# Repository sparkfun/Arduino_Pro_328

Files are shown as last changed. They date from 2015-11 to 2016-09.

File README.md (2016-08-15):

Arduino Pro 328
========================================

Arduino Pro 328

[*Arduino Pro 328 (DEV-10914)*](https://www.sparkfun.com/products/10914)

Arduino Pro does not come with connectors populated so that you can solder in any connector or wire with any orientation you need. 
We recommend first time Arduino users start with the Uno R3. It’s a great board that will get you up and running quickly. 
The Arduino Pro series is meant for users that understand the limitations of system voltage, lack of connectors, and USB off board.

Repository Contents
-------------------

* **/Hardware** - Eagle design files (.brd, .sch)
* **/Production** - Production panel files (.brd)

Documentation
--------------
* **[SparkFun Fritzing repo](https://github.com/sparkfun/Fritzing_Parts)** - Fritzing diagrams for SparkFun products.
* **[SparkFun 3D Model repo](https://github.com/sparkfun/3D_Models)** - 3D models of SparkFun products. 

Product Versions
----------------
* [3.3V/8MHz: DEV-10914](https://www.sparkfun.com/products/10914)- 3.3V/8MHz version of the Arduino Pro. 
* [5V/16MHz: DEV-10915] (https://www.sparkfun.com/products/10915)- 5V/16MHz version of the Arduino Pro. 

Revision History
----------------
Changes to v14 (date code: 8-24-11)
* updated library to increase annular ring size on all thru-hole pads (including package change on buzzer PTH)
* reposition 6x1 serial header to no longer overhang board
* BOM CHANGE - changes smd slide switch to stronger package with side mount tabs

Changes to v15 (date code: 9-21-11)
* changed package on the Buzzer to not include silk

Changes to v16 (date code: 12-20-11)
* Added OSHW logo

Changes to v17
* Added juicy silk graphics

Changes to v18
* Widened hard-to-read silk text

License Information
-------------------

This product is _**open source**_! 

Please review the LICENSE.md file for license information. 

If you have any questions or concerns on licensing, please contact techsupport@sparkfun.com.

Distributed as-is; no warranty is given.

- Your friends at SparkFun.

_**Note:** A portion of this sale is given back to Arduino LLC to help fund continued development of new tools and new IDE features._

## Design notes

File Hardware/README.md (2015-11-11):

Arduino Pro Design Files
=====================================

The .sch and .brd files hare are Eagle CAD schematic and PCB design files from SparkFun Electronics.
A freeware version of Eagle can be found [here](http://www.cadsoftusa.com/download-eagle/freeware/).

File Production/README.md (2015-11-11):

SparkFun Arduino Pro Production Files
=========================================

These are the production files SparkFun uses for printing PCBs.

License Information
-------------------
This product is open source! 

The hardware is released under [Creative Commons ShareAlike 4.0 International](https://creativecommons.org/licenses/by-sa/4.0/).

Please use, reuse, and modify these files as you see fit. Please maintain attribution to SparkFun Electronics and release anything derivative under the same license.

Distributed as-is; no warranty is given.

- Your friends at SparkFun.

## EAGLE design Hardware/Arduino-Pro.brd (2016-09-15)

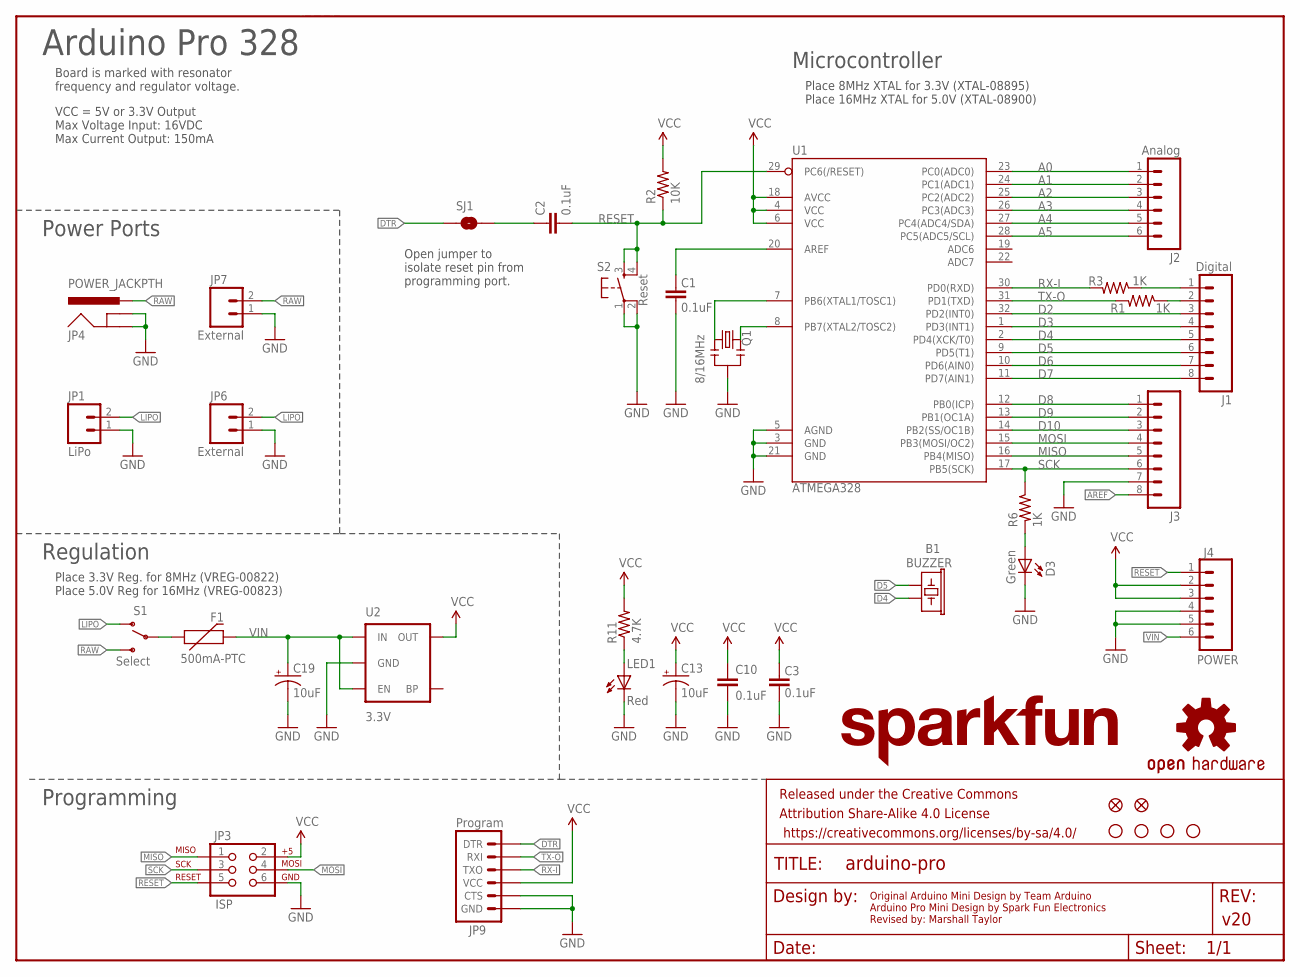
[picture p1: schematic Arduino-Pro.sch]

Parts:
B1: BUZZER; BUZZER-12MM-NS-KIT
C1, C2, C3, C10: 0.1uF; 0402-CAP
C13, C19: 10uF; EIA3216
D3: Green; LED-0603
F1: 500mA-PTC; PTC-1206
FRAME2: FRAME-LETTER; CREATIVE_COMMONS
J1: Digital; 1X08
J2: Analog; 1X06
J3: M081X08; 1X08
J4: POWER; 1X06
JP1: LiPo; JST-2-SMD
JP2, JP5: FIDUCIAL1X2.5; FIDUCIAL-1X2.5
JP3: ISP; 2X3
JP4: POWER_JACKPTH; POWER_JACK_PTH
JP6, JP7: External; 1X02
JP9: Program; 1X06-SMD
LED1: Red; LED-0603
Q1: 8/16MHz; RESONATOR-SMD
R1, R3, R6: 1K; 0402-RES
R2: 10K; 0402-RES
R11: 4.7K; 0402-RES
S1: Select; SWITCH-SPST-SMD-A
S2: Reset; TACTILE_SWITCH_SMD
SJ1: SOLDERJUMPERNC3; SJ_2S-NOTRACE
U1: ATMEGA328; TQFP32-08
U2: 3.3V; SOT23-5
U$1, U$3, U$9, U$10: STAND-OFF

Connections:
A0: J2.1, U1.23 (PC0(ADC0))
A1: J2.2, U1.24 (PC1(ADC1))
A2: J2.3, U1.25 (PC2(ADC2))
A3: J2.4, U1.26 (PC3(ADC3))
A4: J2.5, U1.27 (PC4(ADC4/SDA))
A5: J2.6, U1.28 (PC5(ADC5/SCL))
AREF: C1.2, J3.8, U1.20 (AREF)
D2: J1.3, U1.32 (PD2(INT0))
D3: J1.4, U1.1 (PD3(INT1))
D4: B1.- (2), J1.5, U1.2 (PD4(XCK/T0))
D5: B1.+ (1), J1.6, U1.9 (PD5(T1))
D6: J1.7, U1.10 (PD6(AIN0))
D7: J1.8, U1.11 (PD7(AIN1))
D8: J3.1, U1.12 (PB0(ICP))
D9: J3.2, U1.13 (PB1(OC1A))
D10: J3.3, U1.14 (PB2(SS/OC1B))
DTR: JP9.1 (DTR), SJ1.1
GND: C1.1, C3.1, C10.2, C13.C (-), C19.C (-), D3.C, J3.7, J4.4, J4.5, JP1.1, JP3.6, JP4.GND, JP4.GNDBREAK, JP6.1, JP7.1, JP9.5 (CTS), JP9.6 (GND), LED1.C, Q1.2, S2.1, S2.2, U1.3 (GND), U1.5 (AGND), U1.21 (GND), U2.2 (GND)
LIPO: JP1.2, JP6.2, S1.1 (O)
MISO: J3.5, JP3.1, U1.16 (PB4(MISO))
MOSI: J3.4, JP3.4, U1.15 (PB3(MOSI/OC2))
unnamed: C2.1, SJ1.2
unnamed: Q1.1, U1.8 (PB7(XTAL2/TOSC2))
unnamed: Q1.3, U1.7 (PB6(XTAL1/TOSC1))
unnamed: D3.A, R6.2
unnamed: F1.1, S1.2
unnamed: LED1.A, R11.1
RAW: JP4.PWR, JP7.2, S1.3 (S)
RESET: C2.2, J4.1, JP3.5, R2.1, S2.3, S2.4, U1.29 (PC6(/RESET))
RX-I: JP9.3 (TXO), R3.2, U1.30 (PD0(RXD))
RX-IP: J1.2, R1.1
SCK: J3.6, JP3.3, R6.1, U1.17 (PB5(SCK))
TX-O: JP9.2 (RXI), R1.2, U1.31 (PD1(TXD))
TX-OP: J1.1, R3.1
VCC: C3.2, C10.1, C13.A (+), J4.2, J4.3, JP3.2, JP9.4 (VCC), R2.2, R11.2, U1.4 (VCC), U1.6 (VCC), U1.18 (AVCC), U2.5 (OUT)
VIN: C19.A (+), F1.2, J4.6, U2.1 (IN), U2.3 (EN)

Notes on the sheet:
VCC = 5V or 3.3V Output Max Voltage Input: 16VDC Max Current Output: 150mA
Board is marked with resonator frequency and regulator voltage.
v20
Original Arduino Mini Design by Team Arduino Arduino Pro Mini Design by Spark Fun Electronics Revised by: Marshall Taylor
Power Ports
Regulation
Programming
Microcontroller
Arduino Pro 328
Open jumper to isolate reset pin from programming port.
Place 8MHz XTAL for 3.3V (XTAL-08895) Place 16MHz XTAL for 5.0V (XTAL-08900)
Place 3.3V Reg. for 8MHz (VREG-00822) Place 5.0V Reg for 16MHz (VREG-00823)

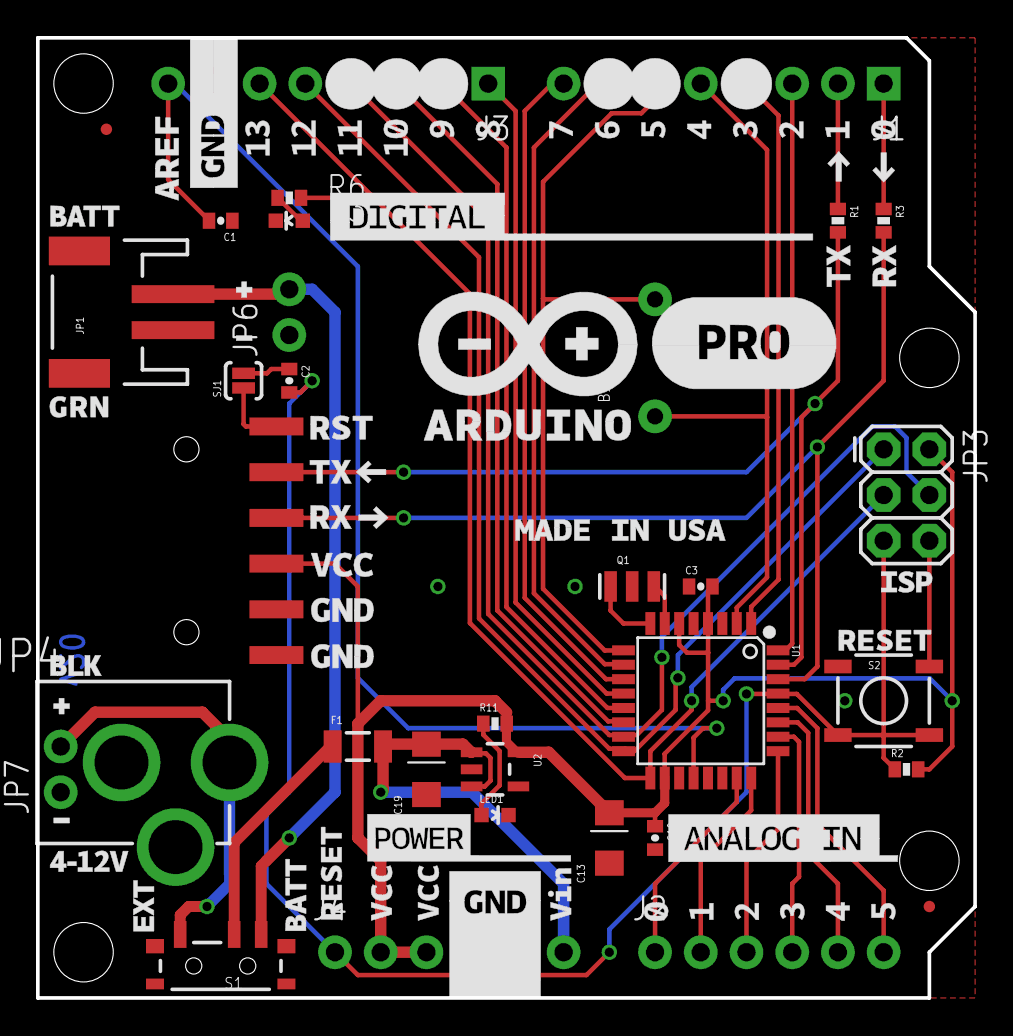
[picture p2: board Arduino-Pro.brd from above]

Board: 2 copper layers, 52.1 x 53.3 mm, 38 parts (0 on the bottom side), 36 nets.

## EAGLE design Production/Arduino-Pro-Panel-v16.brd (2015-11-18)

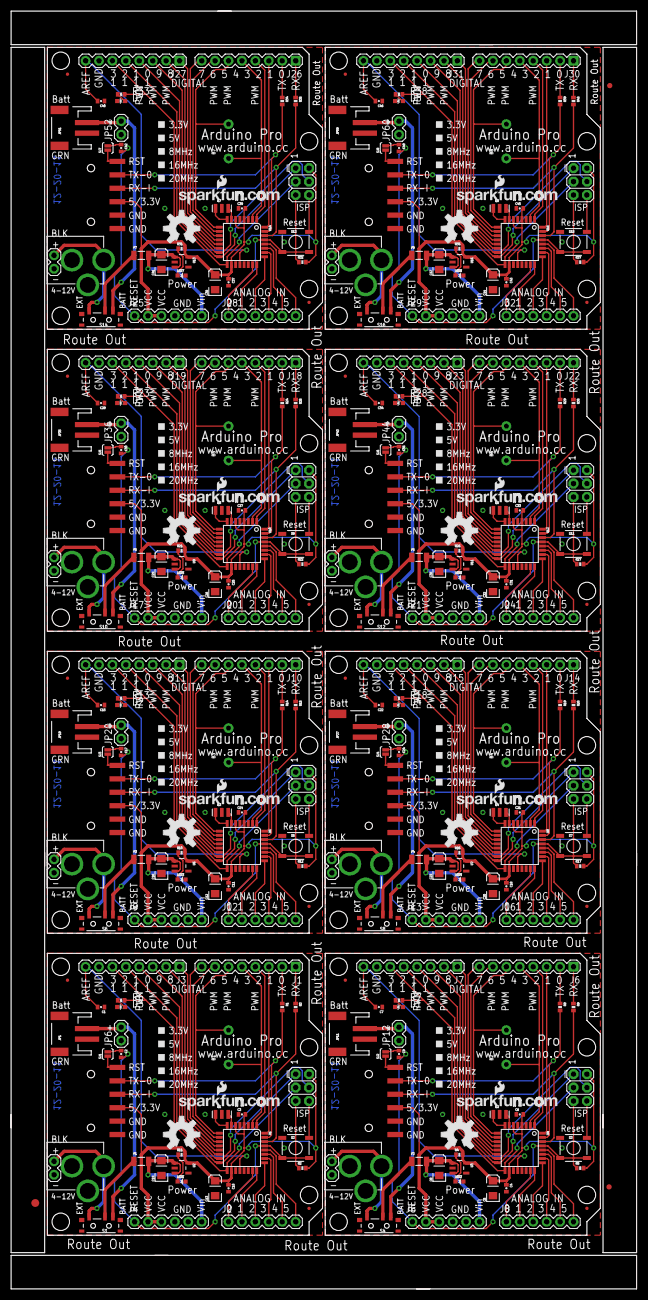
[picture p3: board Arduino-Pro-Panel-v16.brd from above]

Board: 2 copper layers, 118.4 x 241.8 mm, 315 parts (0 on the bottom side), 288 nets.

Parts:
B1, B2, B3, B4, B5, B6, B7, B8: BUZZER; BUZZER-12MM-NS-KIT
C1, C2, C3, C4, C6, C7, C9, C10, C11, C14, C15, C17, C18, C21, C22, C24, C25, C27, C28, C30, C31, C33, C34, C36, C37, C39, C40, C42, C43, C45, C46, C48: 0.1uF; 0402-CAP
C5, C8, C12, C13, C16, C19, C20, C23, C26, C29, C32, C35, C38, C41, C44, C47: 10uF; EIA3216
D1, D2, D3, D4, D5, D6, D7, D8: Green; LED-0603
E$1: FIDUCIAL-1.5X3
E$5, E$7: FIDUCIAL-1X2
F1, F2, F3, F4, F5, F6, F7, F8: 500mA-PTC; PTC-1206
J1, J6, J10, J14, J18, J22, J26, J30: Digital; 1X08
J2, J8, J12, J16, J20, J24, J28, J32: Analog; 1X06
J3, J7, J11, J15, J19, J23, J27, J31: 1X08
J4, J5, J9, J13, J17, J21, J25, J29: POWER; 1X06
JP1, JP11, JP19, JP27, JP35, JP43, JP51, JP59: LiPo; JST-2-SMD
JP2, JP5, JP15, JP16, JP23, JP24, JP31, JP32, JP39, JP40, JP47, JP48, JP55, JP56, JP63, JP64: FIDUCIAL1X2.5; FIDUCIAL-1X2.5
JP3, JP10, JP18, JP26, JP34, JP42, JP50, JP58: ISP; 2X3
JP4, JP8, JP17, JP25, JP33, JP41, JP49, JP57: POWER_JACKPTH; POWER_JACK_PTH
JP6, JP7, JP12, JP13, JP20, JP21, JP28, JP29, JP36, JP37, JP44, JP45, JP52, JP53, JP60, JP61: External; 1X02
JP9, JP14, JP22, JP30, JP38, JP46, JP54, JP62: Program; 1X06-SMD
LED1, LED2, LED3, LED4, LED5, LED6, LED7, LED8: Red; LED-0603
Q1, Q2, Q3, Q4, Q5, Q6, Q7, Q8: RESONATORSMD; RESONATOR-SMD
R1, R3, R6, R7, R8, R9, R13, R14, R15, R18, R19, R20, R23, R24, R25, R28, R29, R30, R33, R34, R35, R38, R39, R40: 1K; 0402-RES
R2, R5, R12, R17, R22, R27, R32, R37: 10K; 0402-RES
R4, R10, R11, R16, R21, R26, R31, R36: 4.7K; 0402-RES
S1, S4, S6, S8, S10, S12, S14, S16: Select; SWITCH-SPST-SMD-A
S2, S3, S5, S7, S9, S11, S13, S15: Reset; TACTILE_SWITCH_SMD
SJ1, SJ2, SJ3, SJ4, SJ5, SJ6, SJ7, SJ8: SOLDERJUMPERNC3; SJ_2S-NOTRACE
U1, U4, U6, U8, U10, U12, U14, U16: ATMEGA328; TQFP32-08
U2, U3, U5, U7, U9, U11, U13, U15: 3.3V; SOT23-5
U$1, U$3, U$4, U$5, U$7, U$8, U$9, U$10, U$13, U$14, U$16, U$17, U$19, U$20, U$22, U$23, U$25, U$26, U$28, U$29, U$31, U$32, U$34, U$35, U$37, U$38, U$40, U$41, U$43, U$44, U$46, U$47: STAND-OFF
U$2, U$12, U$18, U$24, U$30, U$36, U$42, U$48: OSHW-LOGOL; OSHW-LOGO-L
U$6, U$11, U$15, U$21, U$27, U$33, U$39, U$45: LOGO-SFENEW; SFE-NEW-WEBLOGO

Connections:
A0: J2.1, U1.23
A1: J2.2, U1.24
A2: J2.3, U1.25
A3: J2.4, U1.26
A4: J2.5, U1.27
A5: J2.6, U1.28
A6: J8.6, U4.28
A7: J8.5, U4.27
A8: J8.4, U4.26
A9: J8.3, U4.25
A10: J8.2, U4.24
A11: J8.1, U4.23
A12: J12.6, U6.28
A13: J12.5, U6.27
A14: J12.4, U6.26
A15: J12.3, U6.25
A16: J12.2, U6.24
A17: J12.1, U6.23
A18: J16.6, U8.28
A19: J16.5, U8.27
A20: J16.4, U8.26
A21: J16.3, U8.25
A22: J16.2, U8.24
A23: J16.1, U8.23
A24: J20.6, U10.28
A25: J20.5, U10.27
A26: J20.4, U10.26
A27: J20.3, U10.25
A28: J20.2, U10.24
A29: J20.1, U10.23
A30: J24.6, U12.28
A31: J24.5, U12.27
A32: J24.4, U12.26
A33: J24.3, U12.25
A34: J24.2, U12.24
A35: J24.1, U12.23
A36: J28.6, U14.28
A37: J28.5, U14.27
A38: J28.4, U14.26
A39: J28.3, U14.25
A40: J28.2, U14.24
A41: J28.1, U14.23
A42: J32.6, U16.28
A43: J32.5, U16.27
A44: J32.4, U16.26
A45: J32.3, U16.25
A46: J32.2, U16.24
A47: J32.1, U16.23
AREF: C1.2, J3.8, U1.20
AREF1: C7.2, J7.8, U4.20
AREF2: C15.2, J11.8, U6.20
AREF3: C22.2, J15.8, U8.20
AREF4: C28.2, J19.8, U10.20
AREF5: C34.2, J23.8, U12.20
AREF6: C40.2, J27.8, U14.20
AREF7: C46.2, J31.8, U16.20
D1: J7.3, U4.14
D2: J1.3, U1.32
D3: J1.4, U1.1
D4: B1.-, J1.5, U1.2
D5: B1.+, J1.6, U1.9
D6: J1.7, U1.10
D7: J1.8, U1.11
D8: J3.1, U1.12
D9: J3.2, U1.13
D10: J3.3, U1.14
D11: J7.2, U4.13
D12: J7.1, U4.12
D13: J6.8, U4.11
D14: J6.7, U4.10
D15: B2.+, J6.6, U4.9
D16: B2.-, J6.5, U4.2
D17: J6.4, U4.1
D18: J6.3, U4.32
D19: J11.3, U6.14
D20: J11.2, U6.13
D21: J11.1, U6.12
D22: J10.8, U6.11
D23: J10.7, U6.10
D24: B3.+, J10.6, U6.9
D25: B3.-, J10.5, U6.2
D26: J10.4, U6.1
D27: J10.3, U6.32
D28: J15.3, U8.14
D29: J15.2, U8.13
D30: J15.1, U8.12
D31: J14.8, U8.11
D32: J14.7, U8.10
D33: B4.+, J14.6, U8.9
D34: B4.-, J14.5, U8.2
D35: J14.4, U8.1
D36: J14.3, U8.32
D37: J19.3, U10.14
D38: J19.2, U10.13
D39: J19.1, U10.12
D40: J18.8, U10.11
D41: J18.7, U10.10
D42: B5.+, J18.6, U10.9
D43: B5.-, J18.5, U10.2
D44: J18.4, U10.1
D45: J18.3, U10.32
D46: J23.3, U12.14
D47: J23.2, U12.13
D48: J23.1, U12.12
D49: J22.8, U12.11
D50: J22.7, U12.10
D51: B6.+, J22.6, U12.9
D52: B6.-, J22.5, U12.2
D53: J22.4, U12.1
D54: J22.3, U12.32
D55: J27.3, U14.14
D56: J27.2, U14.13
D57: J27.1, U14.12
D58: J26.8, U14.11
D59: J26.7, U14.10
D60: B7.+, J26.6, U14.9
D61: B7.-, J26.5, U14.2
D62: J26.4, U14.1
D63: J26.3, U14.32
D64: J31.3, U16.14
D65: J31.2, U16.13
D66: J31.1, U16.12
D67: J30.8, U16.11
D68: J30.7, U16.10
D69: B8.+, J30.6, U16.9
D70: B8.-, J30.5, U16.2
D71: J30.4, U16.1
D72: J30.3, U16.32
DTR: JP9.1, SJ1.1
DTR1: JP14.1, SJ2.1
DTR2: JP22.1, SJ3.1
DTR3: JP30.1, SJ4.1
DTR4: JP38.1, SJ5.1
DTR5: JP46.1, SJ6.1
DTR6: JP54.1, SJ7.1
DTR7: JP62.1, SJ8.1
GND: C1.1, C3.1, C10.2, C13.C, C19.C, D3.C, J3.7, J4.4, J4.5, JP1.1, JP3.6, JP4.GND, JP4.GNDBREAK, JP6.1, JP7.1, JP9.5, JP9.6, LED1.C, Q1.2, S2.1, S2.2, U1.3, U1.5, U1.21, U2.2
GND1: C4.2, C5.C, C6.1, C7.1, C8.C, D1.C, J5.4, J5.5, J7.7, JP8.GND, JP8.GNDBREAK, JP10.6, JP11.1, JP12.1, JP13.1, JP14.5, JP14.6, LED2.C, Q2.2, S3.1, S3.2, U3.2, U4.3, U4.5, U4.21
GND2: C11.2, C12.C, C14.1, C15.1, C16.C, D2.C, J9.4, J9.5, J11.7, JP17.GND, JP17.GNDBREAK, JP18.6, JP19.1, JP20.1, JP21.1, JP22.5, JP22.6, LED3.C, Q3.2, S5.1, S5.2, U5.2, U6.3, U6.5, U6.21
GND3: C18.2, C20.C, C21.1, C22.1, C23.C, D4.C, J13.4, J13.5, J15.7, JP25.GND, JP25.GNDBREAK, JP26.6, JP27.1, JP28.1, JP29.1, JP30.5, JP30.6, LED4.C, Q4.2, S7.1, S7.2, U7.2, U8.3, U8.5, U8.21
GND4: C25.2, C26.C, C27.1, C28.1, C29.C, D5.C, J17.4, J17.5, J19.7, JP33.GND, JP33.GNDBREAK, JP34.6, JP35.1, JP36.1, JP37.1, JP38.5, JP38.6, LED5.C, Q5.2, S9.1, S9.2, U9.2, U10.3, U10.5, U10.21
GND5: C31.2, C32.C, C33.1, C34.1, C35.C, D6.C, J21.4, J21.5, J23.7, JP41.GND, JP41.GNDBREAK, JP42.6, JP43.1, JP44.1, JP45.1, JP46.5, JP46.6, LED6.C, Q6.2, S11.1, S11.2, U11.2, U12.3, U12.5, U12.21
GND6: C37.2, C38.C, C39.1, C40.1, C41.C, D7.C, J25.4, J25.5, J27.7, JP49.GND, JP49.GNDBREAK, JP50.6, JP51.1, JP52.1, JP53.1, JP54.5, JP54.6, LED7.C, Q7.2, S13.1, S13.2, U13.2, U14.3, U14.5, U14.21
GND7: C43.2, C44.C, C45.1, C46.1, C47.C, D8.C, J29.4, J29.5, J31.7, JP57.GND, JP57.GNDBREAK, JP58.6, JP59.1, JP60.1, JP61.1, JP62.5, JP62.6, LED8.C, Q8.2, S15.1, S15.2, U15.2, U16.3, U16.5, U16.21
LIPO: JP1.2, JP6.2, S1.1
LIPO1: JP11.2, JP12.2, S4.1
LIPO2: JP19.2, JP20.2, S6.1
LIPO3: JP27.2, JP28.2, S8.1
LIPO4: JP35.2, JP36.2, S10.1
LIPO5: JP43.2, JP44.2, S12.1
LIPO6: JP51.2, JP52.2, S14.1
LIPO7: JP59.2, JP60.2, S16.1
MISO: J3.5, JP3.1, U1.16
MISO1: J7.5, JP10.1, U4.16
MISO2: J11.5, JP18.1, U6.16
MISO3: J15.5, JP26.1, U8.16
MISO4: J19.5, JP34.1, U10.16
MISO5: J23.5, JP42.1, U12.16
MISO6: J27.5, JP50.1, U14.16
MISO7: J31.5, JP58.1, U16.16
MOSI: J3.4, JP3.4, U1.15
MOSI1: J7.4, JP10.4, U4.15
MOSI2: J11.4, JP18.4, U6.15
MOSI3: J15.4, JP26.4, U8.15
MOSI4: J19.4, JP34.4, U10.15
MOSI5: J23.4, JP42.4, U12.15
MOSI6: J27.4, JP50.4, U14.15
MOSI7: J31.4, JP58.4, U16.15
unnamed: C2.1, SJ1.2
unnamed: LED2.A, R4.1
unnamed: Q1.1, U1.8
unnamed: Q1.3, U1.7
unnamed: D1.A, R7.2
unnamed: F2.1, S4.2
unnamed: D3.A, R6.2
unnamed: Q2.1, U4.8
unnamed: Q2.3, U4.7
unnamed: C9.1, SJ2.2
unnamed: LED3.A, R10.1
unnamed: D2.A, R13.2
unnamed: F3.1, S6.2
unnamed: Q3.1, U6.8
unnamed: Q3.3, U6.7
unnamed: C17.1, SJ3.2
unnamed: LED4.A, R16.1
unnamed: D4.A, R18.2
unnamed: F4.1, S8.2
unnamed: Q4.1, U8.8
unnamed: Q4.3, U8.7
unnamed: C24.1, SJ4.2
unnamed: LED5.A, R21.1
unnamed: D5.A, R23.2
unnamed: F1.1, S1.2
unnamed: F5.1, S10.2
unnamed: Q5.1, U10.8
unnamed: Q5.3, U10.7
unnamed: C30.1, SJ5.2
unnamed: LED6.A, R26.1
unnamed: D6.A, R28.2
unnamed: F6.1, S12.2
unnamed: Q6.1, U12.8
unnamed: Q6.3, U12.7
unnamed: C36.1, SJ6.2
unnamed: LED7.A, R31.1
unnamed: D7.A, R33.2
unnamed: LED1.A, R11.1
unnamed: F7.1, S14.2
unnamed: Q7.1, U14.8
unnamed: Q7.3, U14.7
unnamed: C42.1, SJ7.2
unnamed: LED8.A, R36.1
unnamed: D8.A, R38.2
unnamed: F8.1, S16.2
unnamed: Q8.1, U16.8
unnamed: Q8.3, U16.7
unnamed: C48.1, SJ8.2
RAW: JP4.PWR, JP7.2, S1.3
RAW1: JP8.PWR, JP13.2, S4.3
RAW2: JP17.PWR, JP21.2, S6.3
RAW3: JP25.PWR, JP29.2, S8.3
RAW4: JP33.PWR, JP37.2, S10.3
RAW5: JP41.PWR, JP45.2, S12.3
RAW6: JP49.PWR, JP53.2, S14.3
RAW7: JP57.PWR, JP61.2, S16.3
RESET: C2.2, J4.1, JP3.5, R2.1, S2.3, S2.4, U1.29
RESET1: C9.2, J5.1, JP10.5, R5.1, S3.3, S3.4, U4.29
RESET2: C17.2, J9.1, JP18.5, R12.1, S5.3, S5.4, U6.29
RESET3: C24.2, J13.1, JP26.5, R17.1, S7.3, S7.4, U8.29
RESET4: C30.2, J17.1, JP34.5, R22.1, S9.3, S9.4, U10.29
RESET5: C36.2, J21.1, JP42.5, R27.1, S11.3, S11.4, U12.29
RESET6: C42.2, J25.1, JP50.5, R32.1, S13.3, S13.4, U14.29
RESET7: C48.2, J29.1, JP58.5, R37.1, S15.3, S15.4, U16.29
RX-I: JP9.3, R3.2, U1.30
RX-I1: JP14.3, R9.2, U4.30
RX-I2: JP22.3, R15.2, U6.30
RX-I3: JP30.3, R20.2, U8.30
RX-I4: JP38.3, R25.2, U10.30
RX-I5: JP46.3, R30.2, U12.30
RX-I6: JP54.3, R35.2, U14.30
RX-I7: JP62.3, R40.2, U16.30
RX-IP: J1.2, R1.1
RX-IP1: J6.2, R8.1
RX-IP2: J10.2, R14.1
RX-IP3: J14.2, R19.1
RX-IP4: J18.2, R24.1
RX-IP5: J22.2, R29.1
RX-IP6: J26.2, R34.1
RX-IP7: J30.2, R39.1
SCK: J3.6, JP3.3, R6.1, U1.17
SCK1: J7.6, JP10.3, R7.1, U4.17
SCK2: J11.6, JP18.3, R13.1, U6.17
SCK3: J15.6, JP26.3, R18.1, U8.17
SCK4: J19.6, JP34.3, R23.1, U10.17
SCK5: J23.6, JP42.3, R28.1, U12.17
SCK6: J27.6, JP50.3, R33.1, U14.17
SCK7: J31.6, JP58.3, R38.1, U16.17
TX-O: JP9.2, R1.2, U1.31
TX-O1: JP14.2, R8.2, U4.31
TX-O2: JP22.2, R14.2, U6.31
TX-O3: JP30.2, R19.2, U8.31
TX-O4: JP38.2, R24.2, U10.31
TX-O5: JP46.2, R29.2, U12.31
TX-O6: JP54.2, R34.2, U14.31
TX-O7: JP62.2, R39.2, U16.31
TX-OP: J1.1, R3.1
TX-OP1: J6.1, R9.1
TX-OP2: J10.1, R15.1
TX-OP3: J14.1, R20.1
TX-OP4: J18.1, R25.1
TX-OP5: J22.1, R30.1
TX-OP6: J26.1, R35.1
TX-OP7: J30.1, R40.1
VCC: C3.2, C10.1, C13.A, J4.2, J4.3, JP3.2, JP9.4, R2.2, R11.2, U1.4, U1.6, U1.18, U2.5
VCC1: C4.1, C5.A, C6.2, J5.2, J5.3, JP10.2, JP14.4, R4.2, R5.2, U3.5, U4.4, U4.6, U4.18
VCC2: C11.1, C12.A, C14.2, J9.2, J9.3, JP18.2, JP22.4, R10.2, R12.2, U5.5, U6.4, U6.6, U6.18
VCC3: C18.1, C20.A, C21.2, J13.2, J13.3, JP26.2, JP30.4, R16.2, R17.2, U7.5, U8.4, U8.6, U8.18
VCC4: C25.1, C26.A, C27.2, J17.2, J17.3, JP34.2, JP38.4, R21.2, R22.2, U9.5, U10.4, U10.6, U10.18
VCC5: C31.1, C32.A, C33.2, J21.2, J21.3, JP42.2, JP46.4, R26.2, R27.2, U11.5, U12.4, U12.6, U12.18
VCC6: C37.1, C38.A, C39.2, J25.2, J25.3, JP50.2, JP54.4, R31.2, R32.2, U13.5, U14.4, U14.6, U14.18
VCC7: C43.1, C44.A, C45.2, J29.2, J29.3, JP58.2, JP62.4, R36.2, R37.2, U15.5, U16.4, U16.6, U16.18
VIN: C19.A, F1.2, J4.6, U2.1, U2.3
VIN1: C8.A, F2.2, J5.6, U3.1, U3.3
VIN2: C16.A, F3.2, J9.6, U5.1, U5.3
VIN3: C23.A, F4.2, J13.6, U7.1, U7.3
VIN4: C29.A, F5.2, J17.6, U9.1, U9.3
VIN5: C35.A, F6.2, J21.6, U11.1, U11.3
VIN6: C41.A, F7.2, J25.6, U13.1, U13.3
VIN7: C47.A, F8.2, J29.6, U15.1, U15.3

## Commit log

2015-11-11 Adding v16 files from Kentro
    [Arduino-Pro-v16.brd, Arduino-Pro-v16.sch]
2015-11-18 created new panel
    [Arduino-Pro-Panel-v16.brd]
2016-07-18 Added test-silk board design and alternate libraries
    [Arduino-Pro-v16_Silk_1.brd, Arduino-Pro-v16_Silk_1.sch]
2016-07-18 Converted to 0.001 width
    [Arduino-Pro-v16_Silk_1.brd]
2016-07-20 Refined silk application
    [Arduino-Pro-v16_No-Silk.brd, Arduino-Pro-v16_No-Silk.sch, Arduino-Pro-v16_Silk_1.brd]
2016-07-21 Finished design review and checklist
    [Arduino-Pro-v16.brd, Arduino-Pro-v16.sch, Arduino-Pro-v16_No-Silk.brd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]
2016-08-02 Updated schematic to standard, moved rev info to readme
    [Arduino-Pro.brd, Arduino-Pro.sch]
2016-08-11 Fixed schematic issues
    [Arduino-Pro.brd, Arduino-Pro.sch]
2016-08-12 Fixed more schematic issues
    [Arduino-Pro.brd, Arduino-Pro.sch]
2016-08-15 Re-imported silk graphics, removed two-pin silk outlines, incremented rev number to 1.8
    [Arduino-Pro.brd, Arduino-Pro.sch]
2016-08-15 Post review and checklist verification
    [Arduino-Pro.brd, Arduino-Pro.sch]
2016-08-17 Added dual-part SKU information in schematic
    [Arduino-Pro.sch]
2016-09-13 Enlarged circles, incremented version number
    [Arduino-Pro.brd, Arduino-Pro.sch]
2016-09-15 Increased zero widths and expanded ordering instructions
    [Arduino-Pro.brd]

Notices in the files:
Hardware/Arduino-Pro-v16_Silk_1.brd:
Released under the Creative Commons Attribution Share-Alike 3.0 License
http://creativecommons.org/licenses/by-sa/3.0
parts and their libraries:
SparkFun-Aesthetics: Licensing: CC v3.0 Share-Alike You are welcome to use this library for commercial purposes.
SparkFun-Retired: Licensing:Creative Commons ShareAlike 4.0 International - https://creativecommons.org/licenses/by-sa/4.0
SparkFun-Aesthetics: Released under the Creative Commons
